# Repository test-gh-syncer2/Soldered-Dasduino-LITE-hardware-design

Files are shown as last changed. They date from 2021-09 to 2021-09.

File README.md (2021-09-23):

## Image

------ product image ------

## Product description

------ product description ------

Find XXXXXXXX on our [web store](https://solde.red/ .

## Repository contents

All Soldered hardware is designed in KiCAD, and repositories are organised in the following way:

- CAD folder - contains KiCAD files (Schematics, Board, Panel Board), organised by version. Change log lists all changes between different versions.
- OUTPUTS - contains useful files, such as Bill of Materials (BOM), PDF of schematics, 3D .step file of the board and gerber files, organised by version. 

## Want to contribute?

All contributions are welcome, feel free to submit the pull request. 

If you discover a bug, please submit an issue or pull request.  

## About Soldered

------ logo -------

At Soldered, we design and manufacture a wide selection of electronic products to help you turn your ideas into acts and bring you one step closer to your final project. Our products are intented for makers and crafted in-house by our experienced team in Osijek, Croatia. We believe that sharing is a crucial element for improvement and innovation, and we work hard to stay connected with all our makers regardless of their skill or experience level. Therefore, all our products are open-source. Finally, we always have your back. If you face any problem concerning either your shopping experience or your electronics project, our team will help you deal with it, offering efficient customer service and cost-free technical support anytime. Some of those might be useful for you:

- [Web Store](https://www.soldered.com)
- [Educational content](https://learn.soldered.com)
- [Community & technical support](https://community.soldered.com)
- [Custom PCBs](https://pcb.soldered.com)

## License info

All Soldered open-source hardware (OSH) is under The TAPR Open Hardware License. Read more in the LICENSE file. 

No warranty - all designs in this repository are distributed in the hope that they will be useful, but without any warranty. They are provided "AS IS", therefore without warranty of any kind, either expressed or implied. The entire quality and performance of what you do with the contents of this repository are your responsibility. In no event, Soldered (TAVU) will be liable for your damages, losses, including any general, special, incidental or consequential damage arising out of the use or inability to use the contents of this repository.

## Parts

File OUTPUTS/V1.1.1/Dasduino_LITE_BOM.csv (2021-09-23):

Id | Designator | Package | Quantity | Designation | Supplier and ref
1 | K4 | HEADER-UPDI | 1 | HEADER-UPDI
2 | ,,,,,,,,,,,,,,,,,,,,,,,,,,,,,,,,,,,,,,,,,,,,,,, | buzzardLabel | 48
3 | R3,R4,R12,R6 | 0402R | 4 | 2k2
4 | G*** | Logo-Back-OSH-3.5mm | 1 | LOGO
5 | D2 | 0402LED | 1 | orange
6 | U4 | SOIC-14 | 1 | ATTINY804
7 | FD1 | FIDUCIAL_1MM_PASTE | 1 | Fiducial_Stencil
8 | D4 | WS2812B-2020 | 1 | WS2812B-2020
9 | D3 | 0402LED | 1 | purple
10 | K5,K6 | HEADER_MALE_8X1 | 2 | HEADER_MALE_8X1
11 | U1 | SOP-16 | 1 | CH340C
12 | K1 | easyC-connector | 1 | easyC-SMD
13 | D1 | 0402LED | 1 | blue
14 | G*** | Symbol-Front-Battery | 1 | LOGO
15 | REF** | Logo-Back-SolderedFULL-13mm | 1 | Logo-Front-SolderedFULL-13mm
16 | G*** | Logo-Front-Soldered-5mm | 1 | LOGO
17 | D5 | 0402LED | 1 | red
18 | SW1,SW2 | YTSA007A0151803B | 2 | YTSA007A0151803B
19 | H1 | HOLE_3.2mm | 1 | HOLE_3.2mm
20 | K3 | JST-2pin-SMD | 1 | JST-2pin-SMD
21 | G*** | Logo-Front-easyC-5mm | 1 | LOGO
22 | G*** | Symbol-Front-USB | 1 | LOGO
23 | K2 | U262-161N-4BVC11 | 1 | U262-161N-4BVC11
24 | R2,R1,R5 | 0603R | 3 | 1k
25 | C9,C1,C10,C2 | 0603C | 4 | 0.1uF
26 | F1 | 1206FUSE | 1 | 1206FUSE-500mA
27 | D6 | M4_DIODA | 1 | M4_DIODA
28 | R10 | 0603R | 1 | 10k
29 | C5,C3,C7,C8 | 0603C | 4 | 2.2uF
30 | R7,R8 | 0603R | 2 | 5.1k
31 | U2 | TPS7A2633DRVR | 1 | TPS7A2633DRVR
32 | REF** | Version1.1.1. | 1 | Version1.1.1.
33 | Q1 | SOT-23-3 | 1 | PMOS-SOT-23-3
34 | R14 | 0603R | 1 | 100k
35 | JP1 | SMD_JUMPER | 1 | SMD_JUMPER
36 | C6 | 0603C | 1 | 270pF
37 | U3 | TP4056M-MSOP8 | 1 | TP4056M
38 | R11 | 0603R | 1 | 3k
39 | C4 | 0603C | 1 | 100nF
40 | D7 | SOD-323 | 1 | BAT20J

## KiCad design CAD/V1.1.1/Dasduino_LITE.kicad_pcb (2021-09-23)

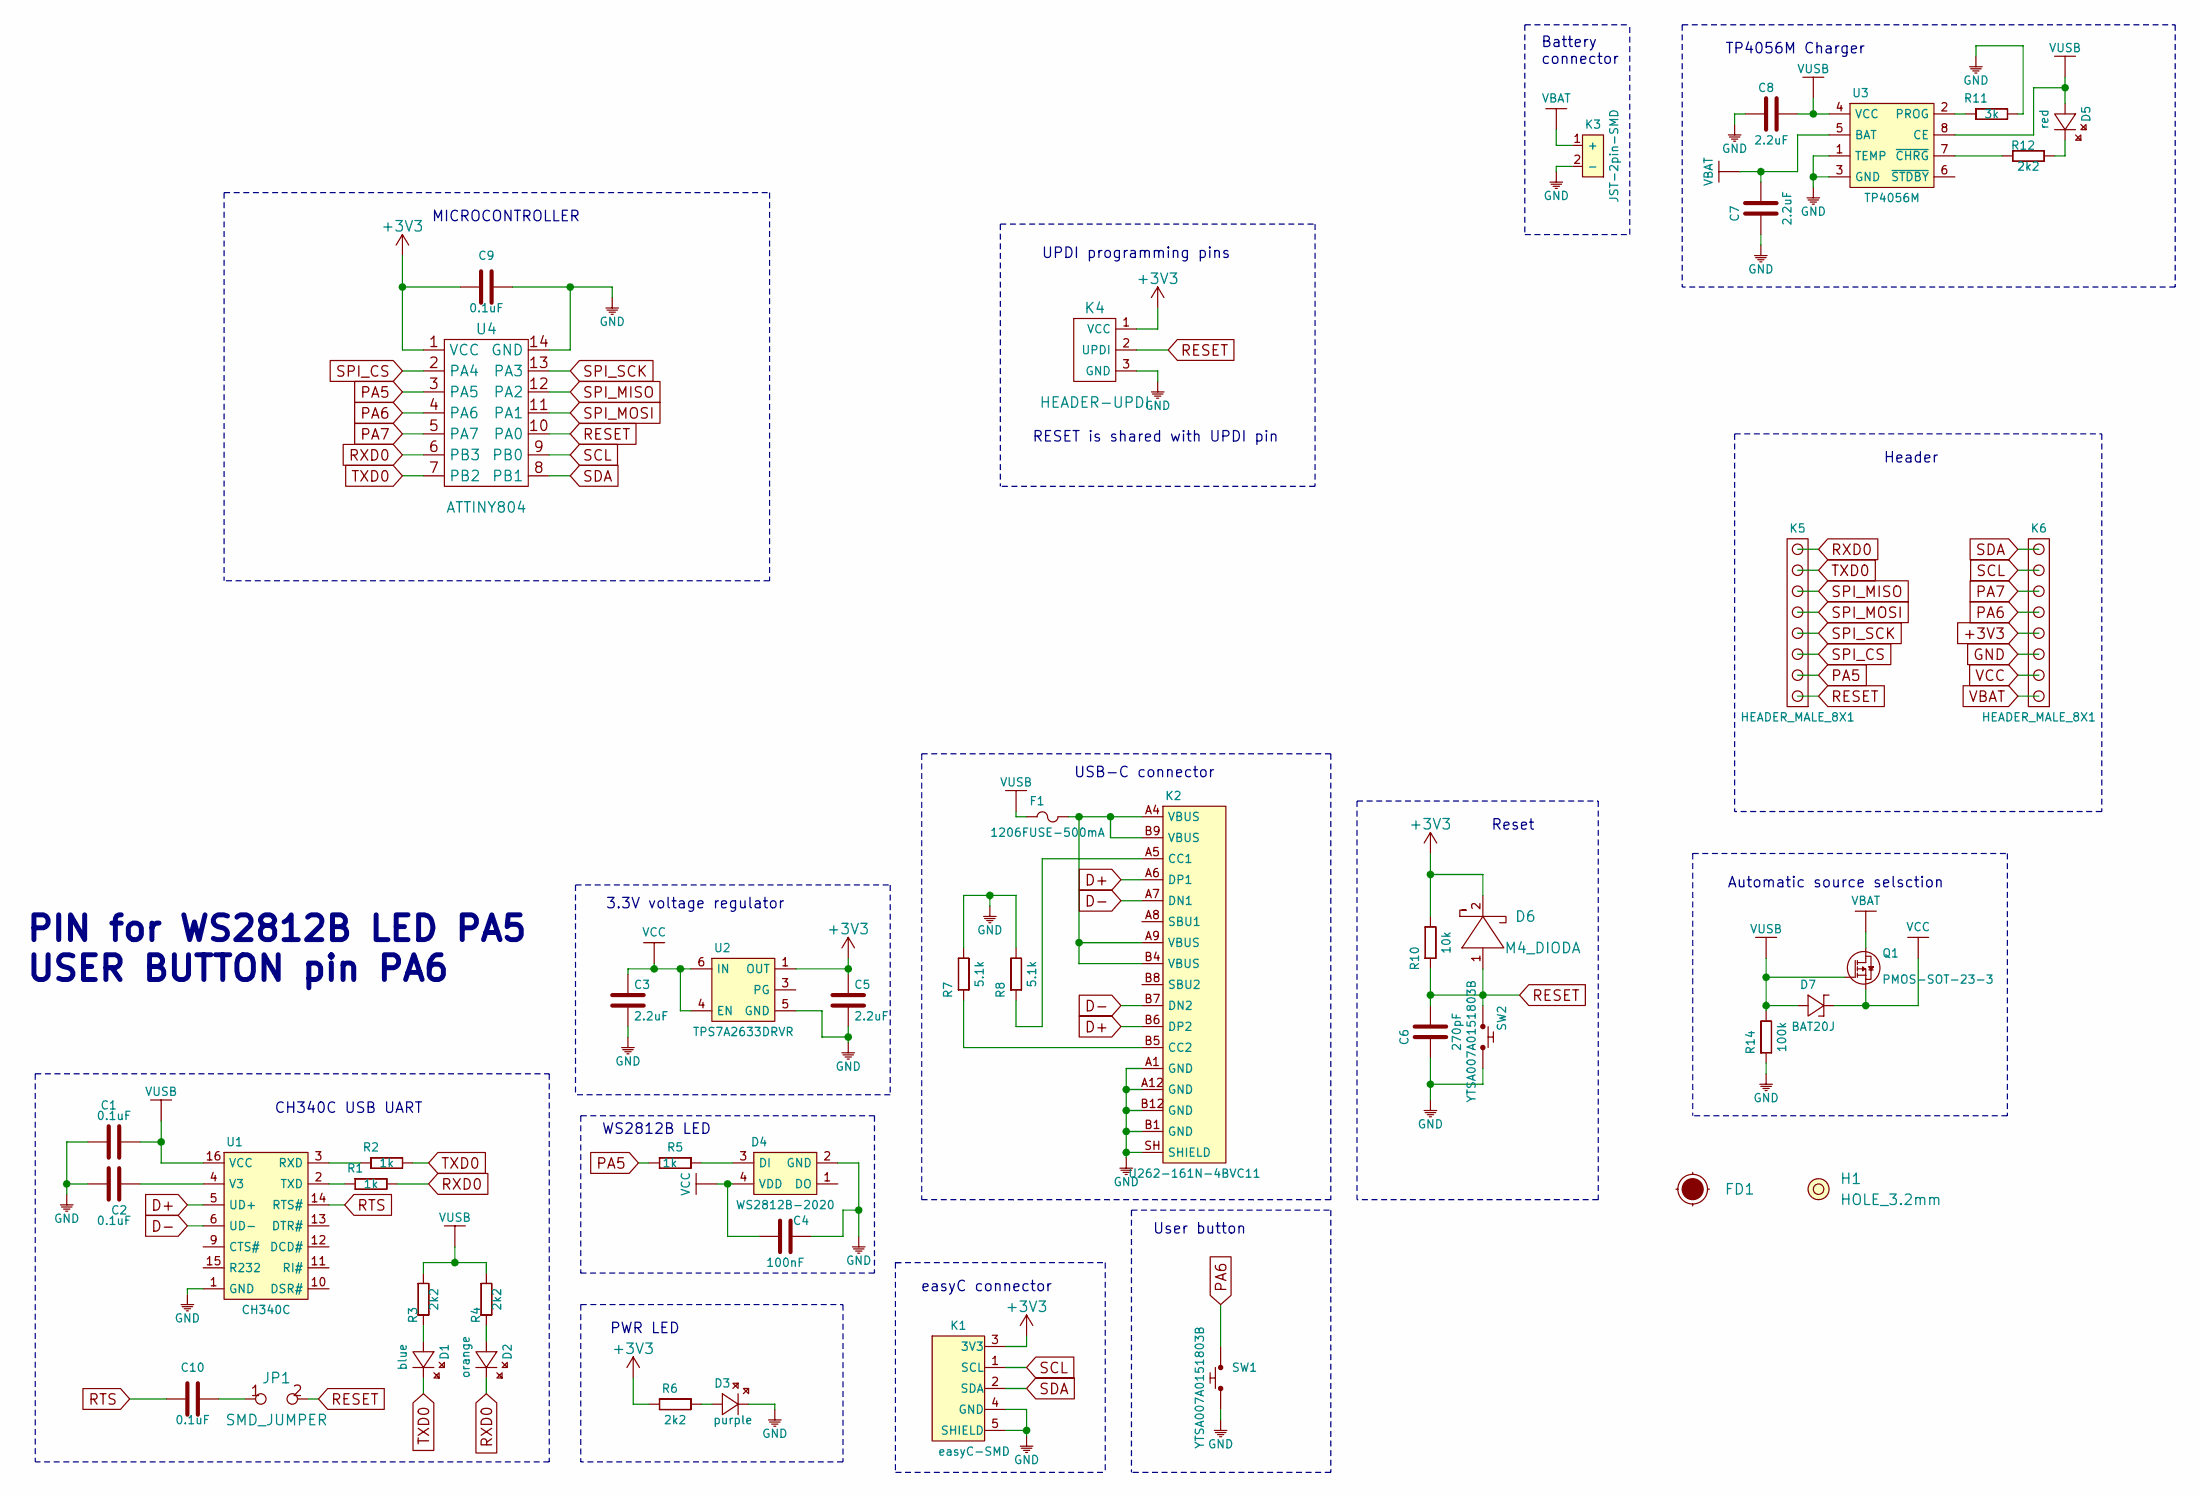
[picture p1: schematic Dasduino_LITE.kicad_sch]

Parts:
C1, C2, C9, C10: 0.1uF; 0603C
C3, C5, C7, C8: 2.2uF; 0603C
C4: 100nF; 0603C
C6: 270pF; 0603C
D1: blue; 0402LED
D2: orange; 0402LED
D3: purple; 0402LED
D4: WS2812B-2020
D5: red; 0402LED
D6: M4_DIODA
D7: BAT20J; SOD-323
F1: 1206FUSE-500mA; 1206FUSE
FD1: Fiducial_Stencil; FIDUCIAL_1MM_PASTE
H1: HOLE_3.2mm
JP1: SMD_JUMPER
K1: easyC-SMD; easyC-connector
K2: U262-161N-4BVC11
K3: JST-2pin-SMD
K4: HEADER-UPDI
K5, K6: HEADER_MALE_8X1
Q1: PMOS-SOT-23-3; SOT-23-3
R1, R2, R5: 1k; 0603R
R3, R4, R6, R12: 2k2; 0402R
R7, R8: 5.1k; 0603R
R10: 10k; 0603R
R11: 3k; 0603R
R14: 100k; 0603R
SW1, SW2: YTSA007A0151803B
U1: CH340C; SOP-16
U2: TPS7A2633DRVR
U3: TP4056M; TP4056M-MSOP8
U4: ATTINY804; SOIC-14

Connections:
+3V3: C5.2, C9.1, D6.2 (K), K1.3 (3V3), K4.1 (VCC), K6.4, R6.1, R10.2, U2.1 (OUT), U4.1 (VCC)
D+: K2.A6 (DP1), K2.B6 (DP2), U1.5 (UD+)
D-: K2.A7 (DN1), K2.B7 (DN2), U1.6 (UD-)
GND: C1.1, C2.2, C3.1, C4.2, C5.1, C6.1, C7.1, C8.1, C9.2, D3.2 (K), D4.2 (GND), K1.4 (GND), K1.5 (SHIELD), K2.A1 (GND), K2.A12 (GND), K2.B1 (GND), K2.B12 (GND), K2.SH (SHIELD), K3.2 (-), K4.3 (GND), K6.3, R7.2, R8.2, R11.2, R14.1, SW1.1, SW2.2, U1.1 (GND), U2.5 (GND), U3.1 (TEMP), U3.3 (GND), U4.14 (GND)
unnamed: C2.1, U1.4 (V3)
unnamed: C10.2, JP1.1
unnamed: D1.1 (A), R3.1
unnamed: D2.1 (A), R4.1
unnamed: D3.1 (A), R6.2
unnamed: D4.3 (DI), R5.2
unnamed: D5.2 (K), R12.2
unnamed: F1.2, K2.A4 (VBUS), K2.A9 (VBUS), K2.B4 (VBUS), K2.B9 (VBUS)
unnamed: K2.A5 (CC1), R8.1
unnamed: K2.B5 (CC2), R7.1
unnamed: R1.1, U1.2 (TXD)
unnamed: R2.1, U1.3 (RXD)
unnamed: R11.1, U3.2 (PROG)
unnamed: R12.1, U3.7 (~CHRG)
PA5: K5.2, R5.1, U4.3 (PA5)
PA6: K6.5, SW1.2, U4.4 (PA6)
PA7: K6.6, U4.5 (PA7)
RESET: C6.2, D6.1 (A), JP1.2, K4.2 (UPDI), K5.1, R10.1, SW2.1, U4.10 (PA0)
RTS: C10.1, U1.14 (RTS#)
RXD0: D2.2 (K), K5.8, R1.2, U4.6 (PB3)
SCL: K1.1 (SCL), K6.7, U4.9 (PB0)
SDA: K1.2 (SDA), K6.8, U4.8 (PB1)
SPI_CS: K5.3, U4.2 (PA4)
SPI_MISO: K5.6, U4.12 (PA2)
SPI_MOSI: K5.5, U4.11 (PA1)
SPI_SCK: K5.4, U4.13 (PA3)
TXD0: D1.2 (K), K5.7, R2.2, U4.7 (PB2)
VBAT: C7.2, K3.1 (+), K6.1, Q1.3 (D), U3.5 (BAT)
VCC: C3.2, C4.1, D4.4 (VDD), D7.2 (K), K6.2, Q1.2 (S), U2.4 (EN), U2.6 (IN)
VUSB: C1.2, C8.2, D5.1 (A), D7.1 (A), F1.1, Q1.1 (G), R3.2, R4.2, R14.2, U1.16 (VCC), U3.4 (VCC), U3.8 (CE)

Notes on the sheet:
PIN for WS2812B LED PA5 USER BUTTON pin PA6
CH340C USB UART
MICROCONTROLLER
PWR LED
WS2812B LED
3.3V voltage regulator
RESET is shared with UPDI pin
easyC connector
USB-C connector
UPDI programming pins
User button
Reset
Battery connector
TP4056M Charger
Header
Automatic source selsction

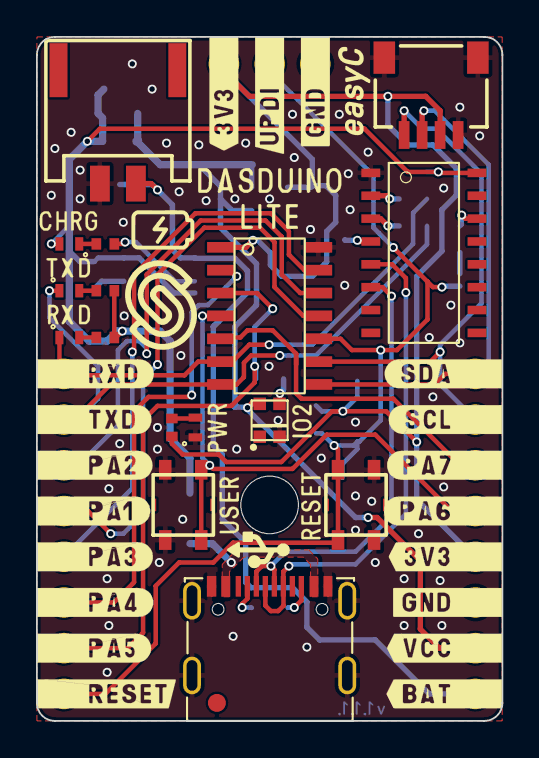
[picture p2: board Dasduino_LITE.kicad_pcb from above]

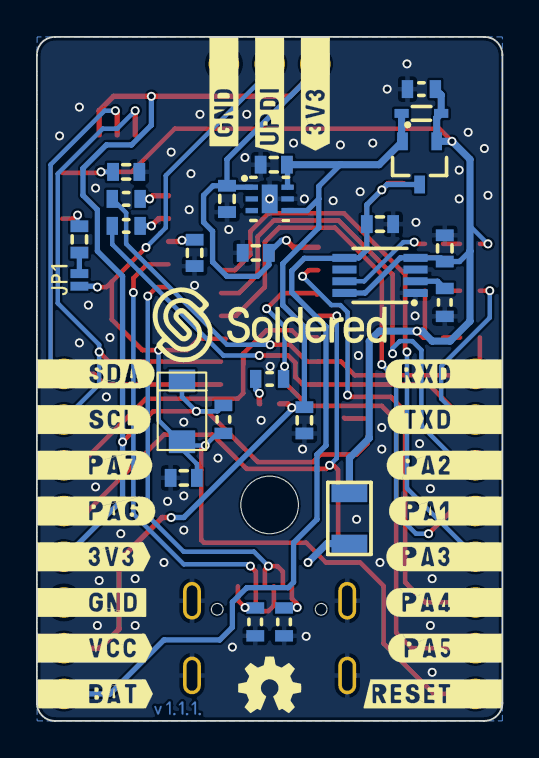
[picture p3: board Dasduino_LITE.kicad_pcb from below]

Board: 2 copper layers, 25.9 x 38.0 mm, 46 parts (25 on the bottom side), 34 nets.

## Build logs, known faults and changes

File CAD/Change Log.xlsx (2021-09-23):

CHANGE LOG
 | Latest version |  |  | v1.1.1.
 |  | Product name: |  | Dasduino LITE
 |  | Release date: |  | 29.6.2021.
 |  | Release author: |  | Ivan
Version: | v1.0.0. | Author: | Ivan | Date: | 29.4.2021.
List of Changes
 | Initial document
Version: | v1.1.1. | Author: | Ivan | Date: | 29.6.2021.
List of Changes
 | stavljen veći logo na zadnju stranu
 | GND i VCC oznake ispravljene (krivi redosljed)
 | Stavljena veća oznaka za jumper
 | otpornici za ledice stavljeni 2k2
 | stavljen 100nF za WS2812B
 | .
